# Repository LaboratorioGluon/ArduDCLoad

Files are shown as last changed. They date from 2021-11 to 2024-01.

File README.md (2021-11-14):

# ArduDCLoad	

A configurable multipurpose DC Load board developed directly [on Twitch](https://www.twitch.tv/labgluon)

The values of the resistors can be calculated to adapt the PCB to your needs.

With defaul values máximum values are:
- V_TEST: 15V, 3A
- V_In; 5V

And this is how it looks:

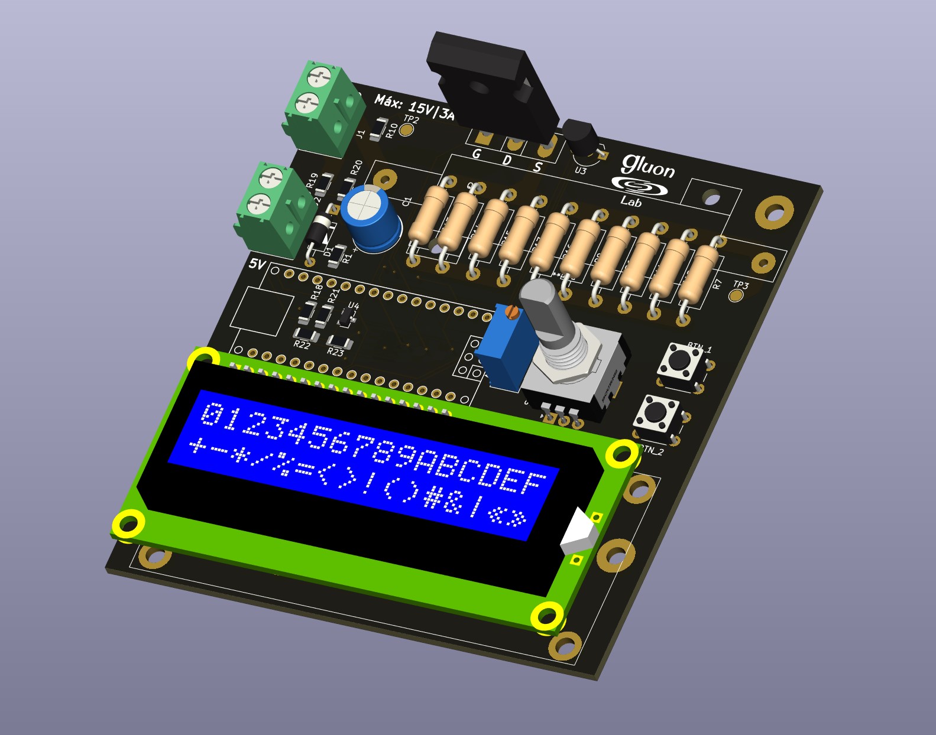
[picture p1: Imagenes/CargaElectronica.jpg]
PCB Image


# Design and customization

Here we will see how to customize the circuit for our need. The ADCL (ArduDCLoad) can be configure to mount a beefy TO-247 or small TO-220 MOSFETS. Also, it also contains the footprint for 10 resistors( L: 10mm, D: 3.6mm, P:15mm) or big chunky wirewound resistor (L:50mm, W:14mm).

Lets see how to adapt it to your need (we will calculate the values for the current values in the design)

## Select V_TEST and I_TEST

Set what do you need for V_TEST and I_TEST. The circuit can only support **around 5-6A** máximum.

In our case

> V_TEST = 15V
> I_TEST = 3A

## Select MOSFET measuring resistor

The ideal values would be between 1 to 0.1 Ohms. The lower the current you expect, the bigget the value should be. In our case, for 3A, with 1 Ohm, we have 3V drop, so we can go with 1 Ohm. (We expect to test more than 3V)

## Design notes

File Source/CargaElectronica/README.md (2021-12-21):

# Design

The software is splitted into 3 components:
- Input : Handling the inputs of the buttons/rotary encoder
- Screen : Send the data to the screen and handle the info and display
- DcLoad : Control the PWM output to control the actual DC Load

# Project Structure + Conventions

- src/
    - taskInput/
        - mainInput.cpp/h
    - taskScreen/
        - mainScreen.cpp/h
    - taskDcLoad/
        - mainDcLoad.cpp/h
    - taskConfig.h
    - globalConfig.h
    - main.cpp

## Tasks

Each task will have a structure with the data it can gather. `struct <component>Data;`

## Naming

```
<component><part>()
ie: inputMainLoop()

```

# System
The system will be Arduino Nano AtMega328p

ADCs:
Interrupts: 

# Components

## Input

- Data:
    - RotaryPulses
    - PushButtons[2]
    - ADC read.
- Period: 100 ms
- Interrupts:
    - 

## Screen

- Data: 
    - Current Mode
    - Current/Power value set.
- Period: 300 ms

### Screens

#### Welcome

Print something like 

---------------
"  Welcome!  "
" ArduDCLoad "
---------------

#### 

## DcLoad

- Data: None
- Period: 50 ms

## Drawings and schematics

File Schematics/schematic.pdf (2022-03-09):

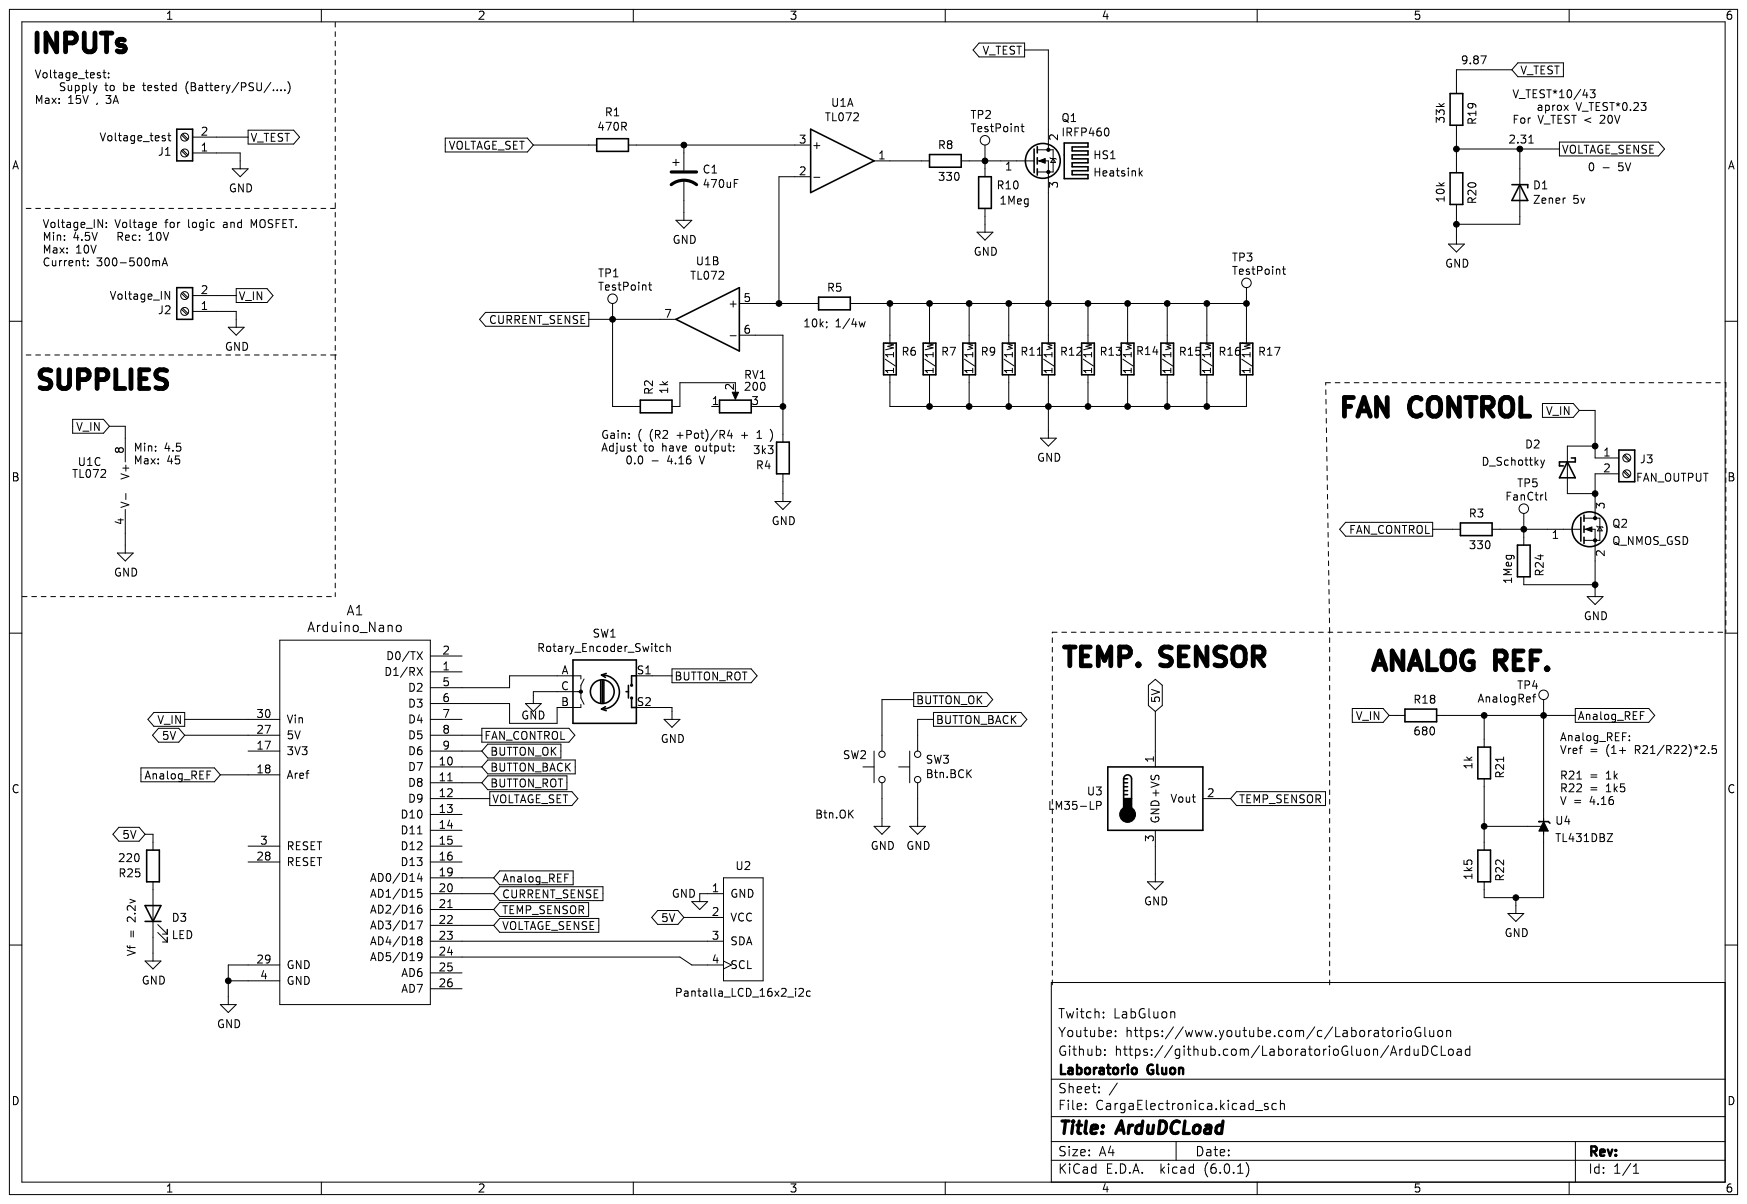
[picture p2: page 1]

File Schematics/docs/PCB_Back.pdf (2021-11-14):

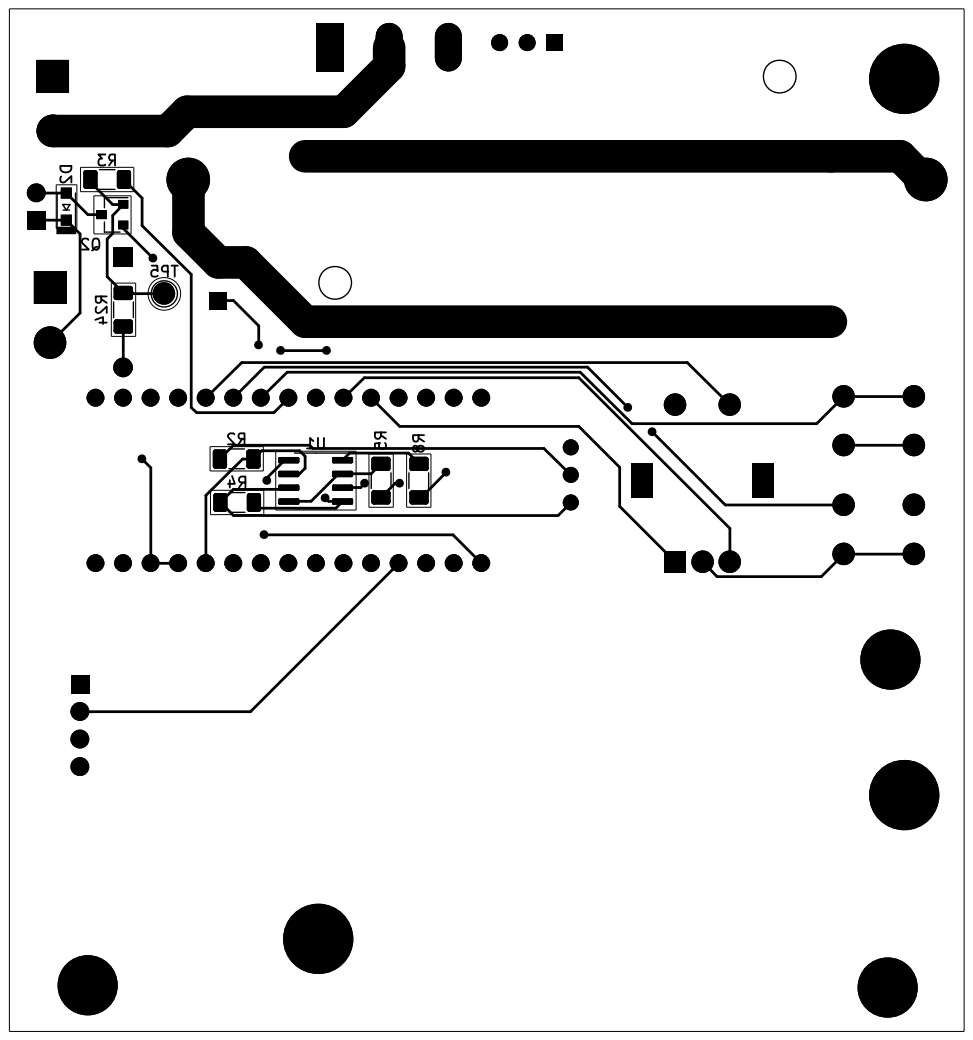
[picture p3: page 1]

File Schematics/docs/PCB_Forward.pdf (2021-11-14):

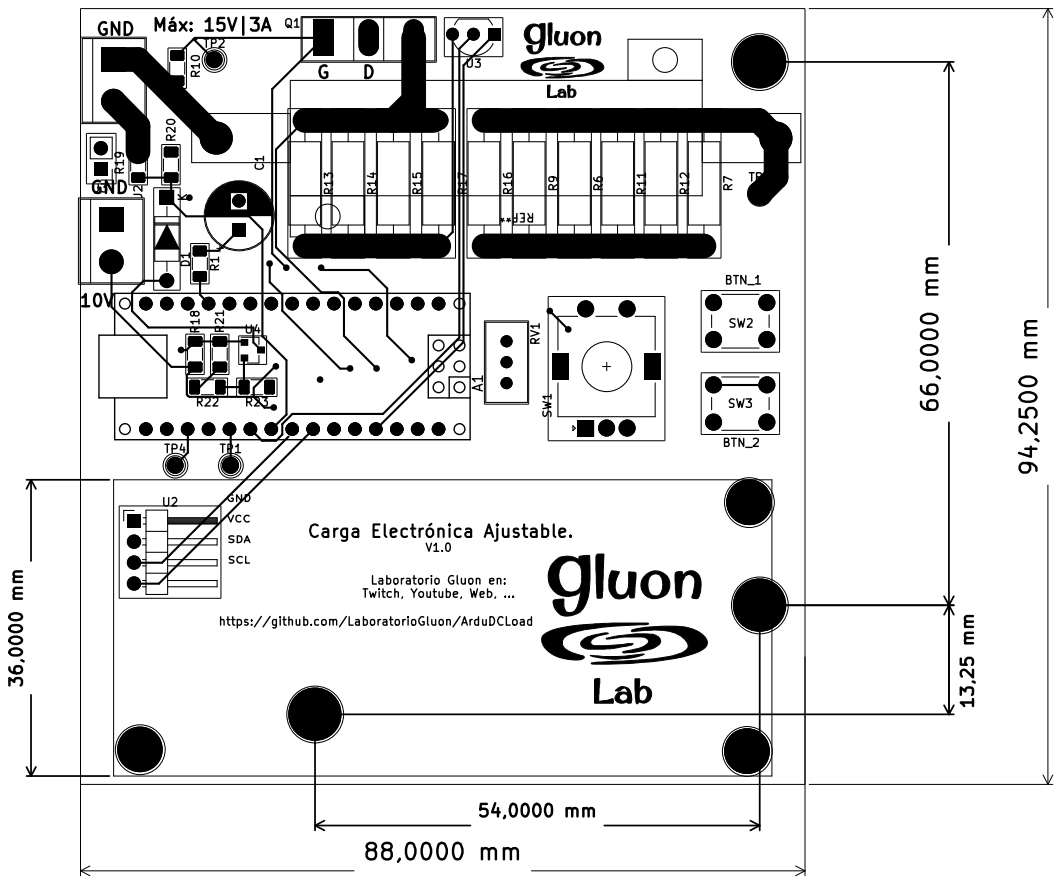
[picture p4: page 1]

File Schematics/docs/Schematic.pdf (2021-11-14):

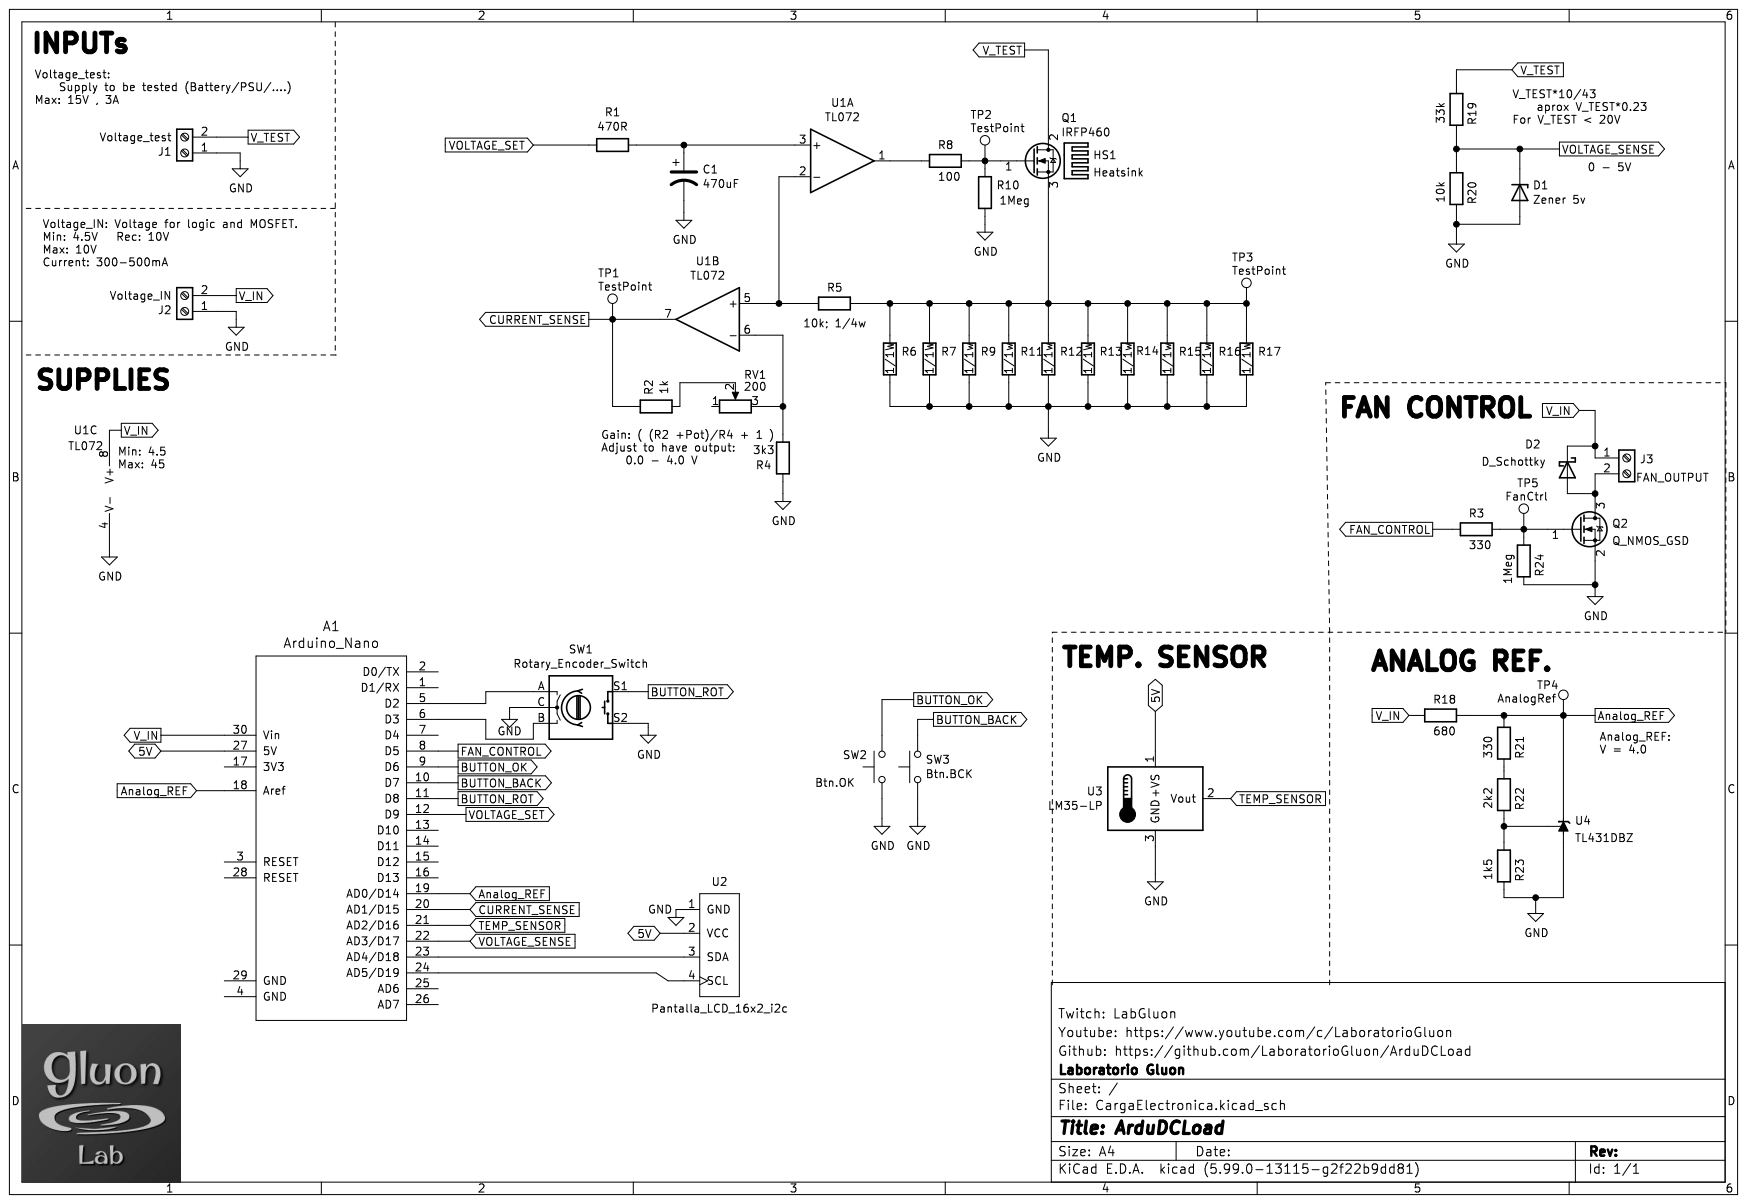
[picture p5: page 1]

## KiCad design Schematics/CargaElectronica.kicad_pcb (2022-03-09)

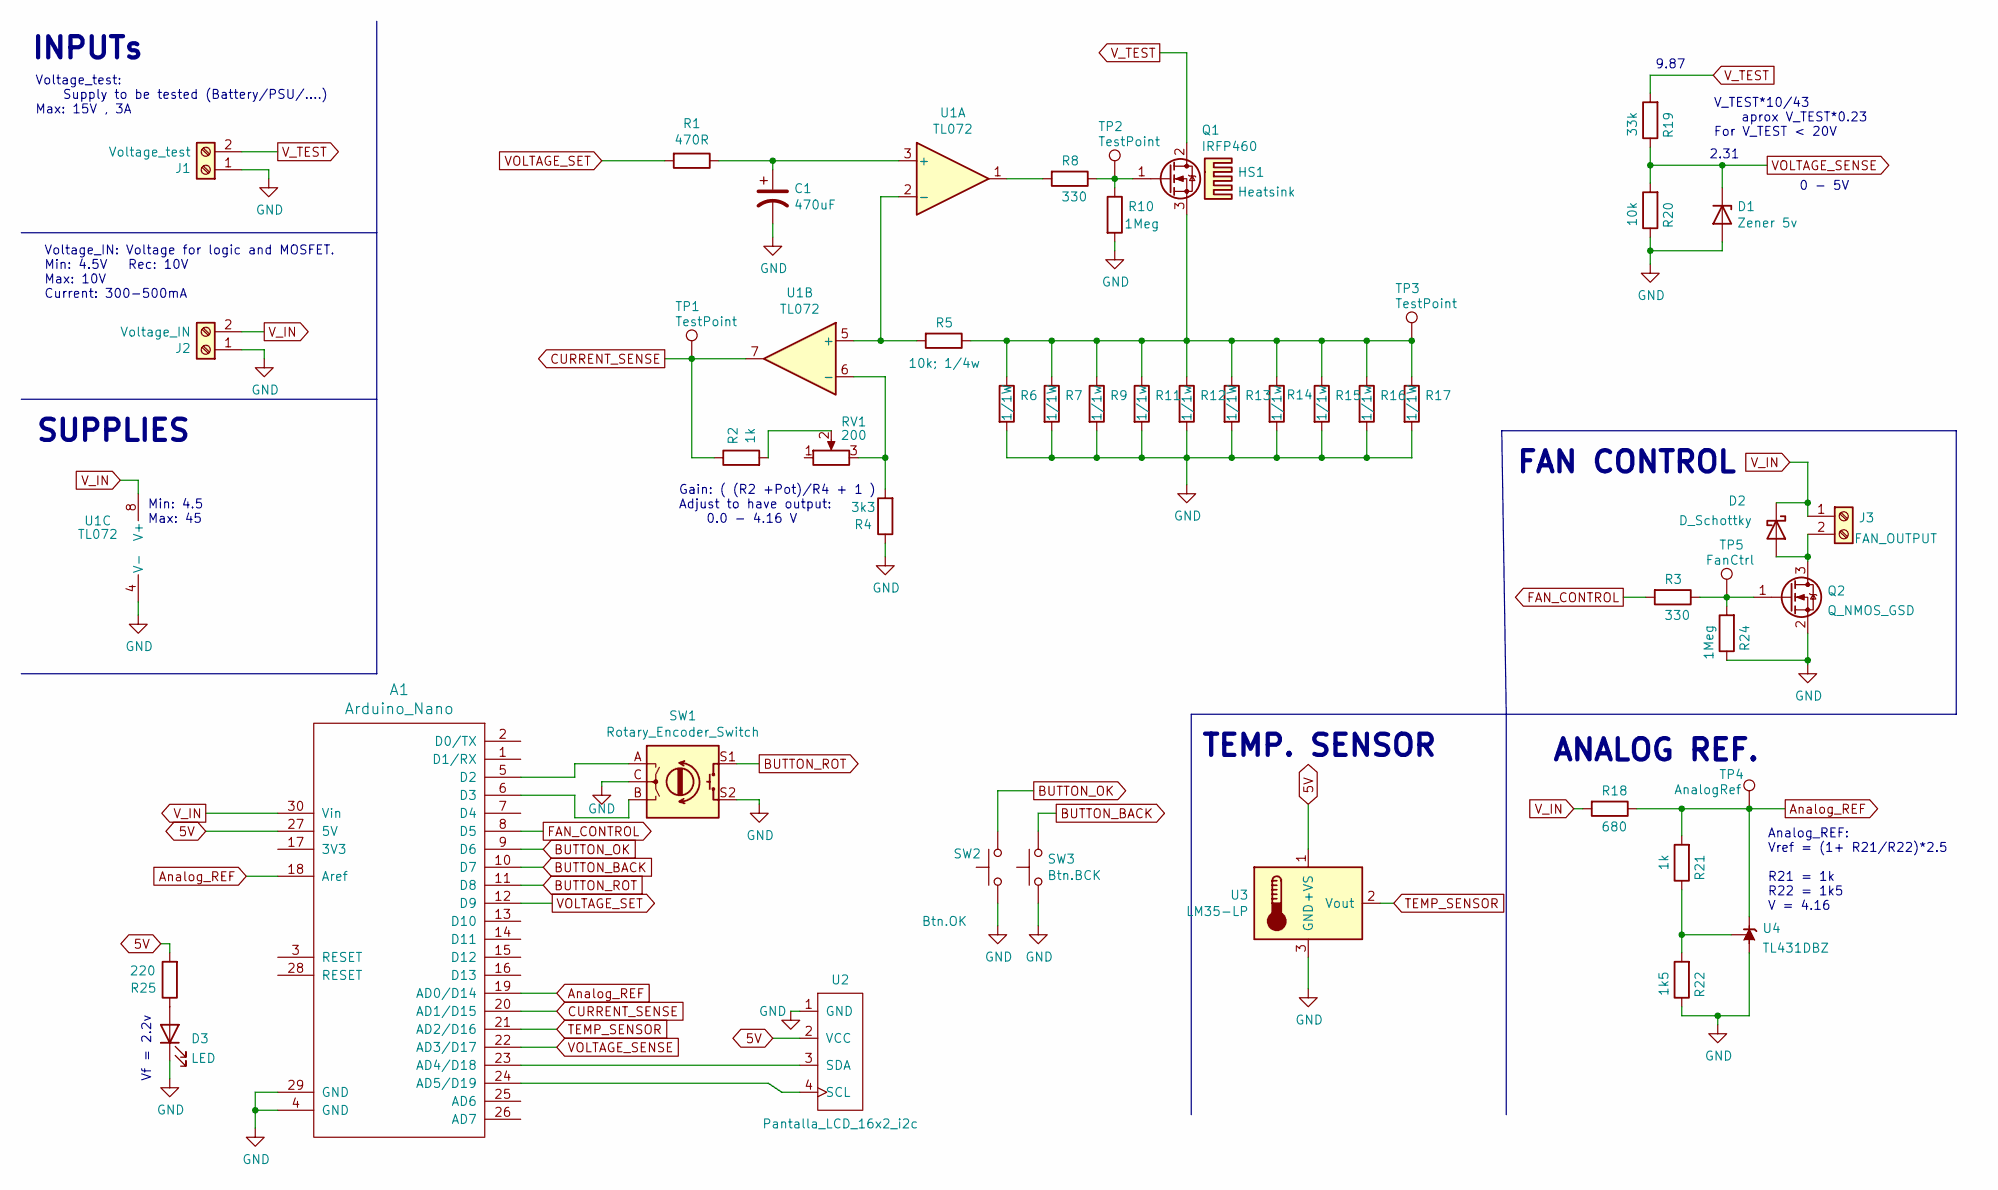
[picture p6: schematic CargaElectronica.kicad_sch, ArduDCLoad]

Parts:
A1: Arduino_Nano; arduino_nano
C1: 470uF; CP_Radial_D8.0mm_P3.50mm
D1: Zener 5v; D_A-405_P10.16mm_Horizontal
D2: D_Schottky; D_SOD-323_HandSoldering
D3: LED; LED_D5.0mm_Horizontal_O1.27mm_Z3.0mm
HS1: Heatsink
J1: Voltage_test; TerminalBlock_bornier-2_P5.08mm
J2: Voltage_IN; TerminalBlock_bornier-2_P5.08mm
J3: FAN_OUTPUT; PinHeader_1x02_P2.54mm_Vertical
Q1: IRFP460; TO-247-3_Vertical
Q2: Q_NMOS_GSD; SOT-23
R1: 470R; R_1206_3216Metric_Pad1.30x1.75mm_HandSolder
R2, R21: 1k; R_1206_3216Metric_Pad1.30x1.75mm_HandSolder
R3, R8: 330; R_1206_3216Metric_Pad1.30x1.75mm_HandSolder
R4: 3k3; R_1206_3216Metric_Pad1.30x1.75mm_HandSolder
R5: 10k; 1/4w; R_1206_3216Metric_Pad1.30x1.75mm_HandSolder
R6, R7, R13, R17: 1/1W; R_Axial_DIN0411_L9.9mm_D3.6mm_P15.24mm_Horizontal
R9, R11, R12, R14, R15, R16: 1/1w; R_Axial_DIN0411_L9.9mm_D3.6mm_P15.24mm_Horizontal
R10, R24: 1Meg; R_1206_3216Metric_Pad1.30x1.75mm_HandSolder
R18: 680; R_1206_3216Metric_Pad1.30x1.75mm_HandSolder
R19: 33k; R_1206_3216Metric_Pad1.30x1.75mm_HandSolder
R20: 10k; R_1206_3216Metric_Pad1.30x1.75mm_HandSolder
R22: 1k5; R_1206_3216Metric_Pad1.30x1.75mm_HandSolder
R25: 220; R_1206_3216Metric_Pad1.30x1.75mm_HandSolder
RV1: 200; Potentiometer_Bourns_3296W_Vertical
SW1: Rotary_Encoder_Switch; RotaryEncoder_Alps_EC11E-Switch_Vertical_H20mm
SW2: Btn.OK; SW_PUSH_6mm_H4.3mm
SW3: Btn.BCK; SW_PUSH_6mm_H4.3mm
TP1, TP2, TP3: TestPoint; TestPoint_Pad_D2.0mm
TP4: AnalogRef; TestPoint_Pad_D2.0mm
TP5: FanCtrl; TestPoint_Pad_D2.0mm
U1: TL072; SOIC-8_3.9x4.9mm_P1.27mm
U2: Pantalla_LCD_16x2_i2c; PinHeader_1x04_P2.54mm_Horizontal
U3: LM35-LP; TO-92_Inline_Wide
U4: TL431DBZ; SOT-23

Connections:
5V: A1.27 (5V), R25.2, U2.2 (VCC), U3.1 (+VS)
Analog_REF: A1.18 (Aref), A1.19 (AD0/D14), R18.1, R21.2, TP4.1, U4.1 (K)
BUTTON_BACK: A1.10 (D7), SW3.2
BUTTON_OK: A1.9 (D6), SW2.2
BUTTON_ROT: A1.11 (D8), SW1.S1
CURRENT_SENSE: A1.20 (AD1/D15), R2.1, TP1.1, U1.7
FAN_CONTROL: A1.8 (D5), R3.2
GND: A1.4 (GND), A1.29 (GND), C1.2, D1.2 (A), D3.1 (K), J1.1, J2.1, Q2.2 (S), R4.1, R6.2, R7.2, R9.2, R10.2, R11.2, R12.2, R13.2, R14.2, R15.2, R16.2, R17.2, R20.1, R22.1, R24.1, SW1.C, SW1.S2, SW2.1, SW3.1, U1.4 (V-), U2.1 (GND), U3.3 (GND), U4.3 (A)
unnamed: A1.5 (D2), SW1.A
unnamed: A1.6 (D3), SW1.B
unnamed: A1.23 (AD4/D18), U2.3 (SDA)
unnamed: A1.24 (AD5/D19), U2.4 (SCL)
unnamed: C1.1, R1.1, U1.3 (+)
unnamed: D2.2 (A), J3.2, Q2.3 (D)
unnamed: D3.2 (A), R25.1
unnamed: Q1.1 (G), R8.1, R10.1, TP2.1
unnamed: Q1.3 (S), R5.1, R6.1, R7.1, R9.1, R11.1, R12.1, R13.1, R14.1, R15.1, R16.1, R17.1, TP3.1
unnamed: Q2.1 (G), R3.1, R24.2, TP5.1
unnamed: R2.2, RV1.2
unnamed: R4.2, RV1.3, U1.6 (-)
unnamed: R5.2, U1.2 (-), U1.5 (+)
unnamed: R8.2, U1.1
unnamed: R21.1, R22.2, U4.2 (REF)
TEMP_SENSOR: A1.21 (AD2/D16), U3.2 (Vout)
VOLTAGE_SENSE: A1.22 (AD3/D17), D1.1 (K), R19.1, R20.2
VOLTAGE_SET: A1.12 (D9), R1.2
V_IN: A1.30 (Vin), D2.1 (K), J2.2, J3.1, R18.2, U1.8 (V+)
V_TEST: J1.2, Q1.2 (D), R19.2

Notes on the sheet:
Min: 4.5 Max: 45
Vf = 2.2v
ANALOG REF.
INPUTs
9.87
V_TEST*10/43 aprox V_TEST*0.23 For V_TEST < 20V
2.31
TEMP. SENSOR
Voltage_test: Supply to be tested (Battery/PSU/....) Max: 15V , 3A
FAN CONTROL
SUPPLIES
Voltage_IN: Voltage for logic and MOSFET. Min: 4.5V Rec: 10V Max: 10V Current: 300-500mA
Analog_REF: Vref = (1+ R21/R22)*2.5 R21 = 1k R22 = 1k5 V = 4.16
Gain: ( (R2 +Pot)/R4 + 1 ) Adjust to have output: 0.0 - 4.16 V
0 - 5V

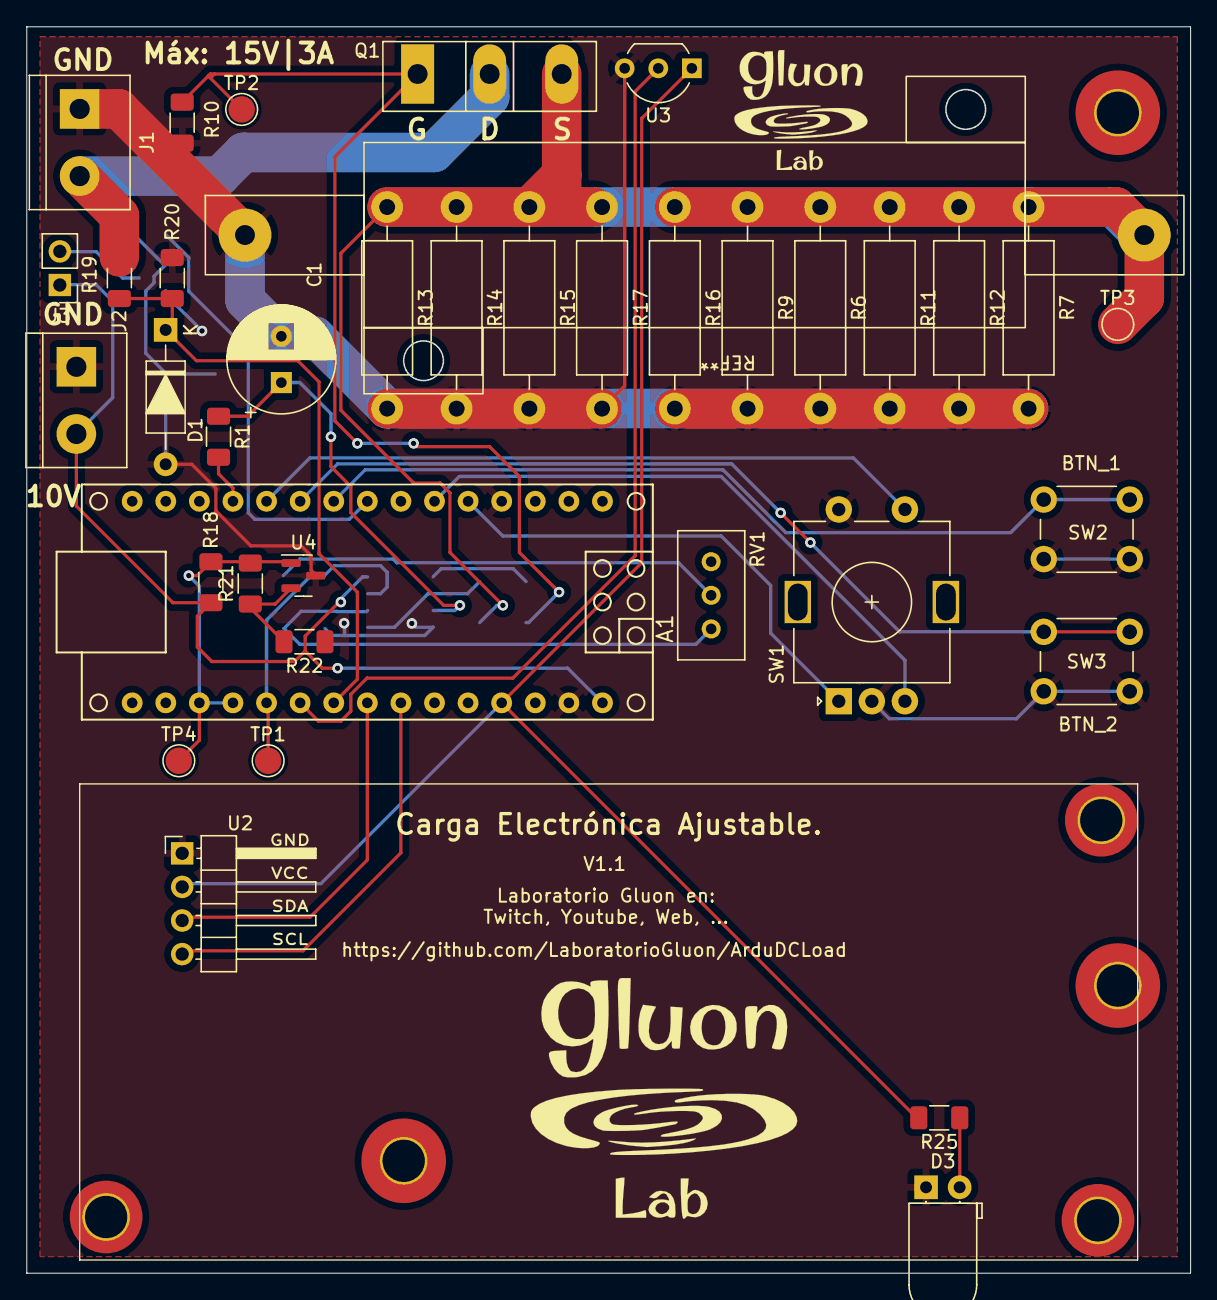
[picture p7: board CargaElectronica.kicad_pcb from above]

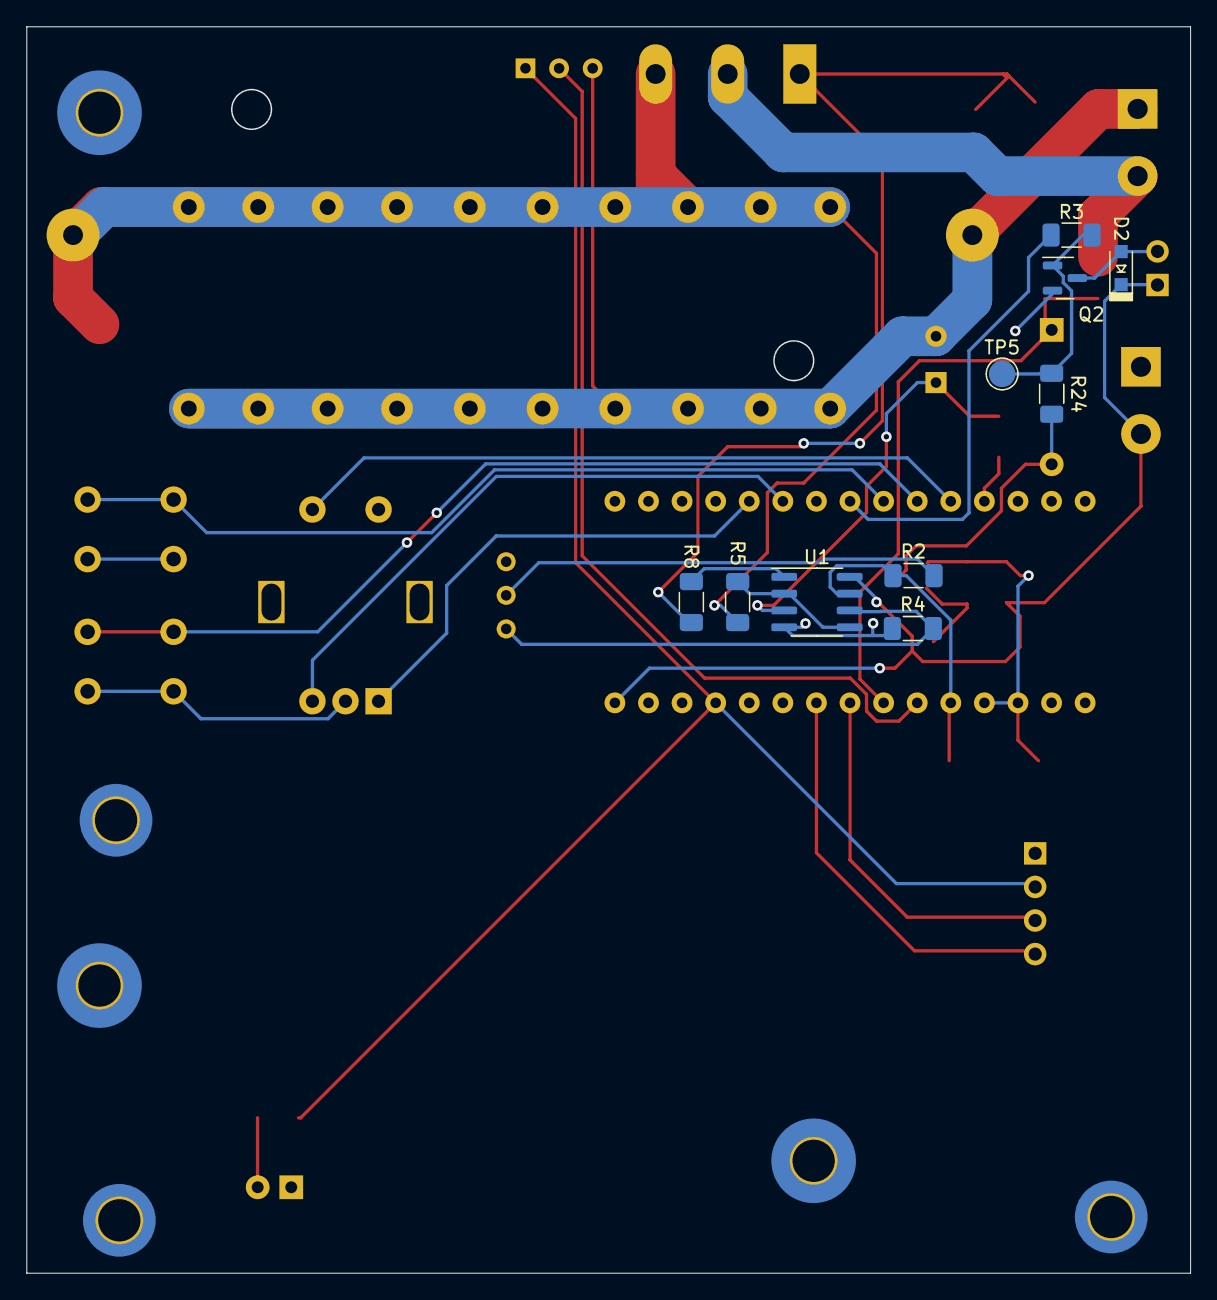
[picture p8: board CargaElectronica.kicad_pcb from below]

Board: 2 copper layers, 88.0 x 94.2 mm, 47 parts (10 on the bottom side), 28 nets.

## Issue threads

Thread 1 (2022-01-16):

Reference voltage circuit is not correct.

LaboratorioGluon, 2022-01-16:
The Reference voltage with the TL431 is not correct.

The Vout equation is Vo = (1 + R1/R2)*Vref.

The current configuration is:
- R1: 2500
- R2: 1500

The Vo is then 6.6V aprox.

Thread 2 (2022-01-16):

Missing ground for Arduino

LaboratorioGluon, 2022-01-16:
The Arduino socket does not have a ground connection.

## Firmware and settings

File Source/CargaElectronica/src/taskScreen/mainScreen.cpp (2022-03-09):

#include "taskScreen/mainScreen.h"
#include "taskScreen/screenTemplates.h"

#include <Arduino.h>

#include <Wire.h>
#include <LiquidCrystal_I2C.h>

#include <stdint.h>

#include "taskInput/mainInput.h"

#include "FSM/fsm.h"

constexpr unsigned long ScreenPeriodMs = 300; // 100ms 

namespace taskScreen {

    struct screenData screenOutData;

    enum screenState {
        SCREEN_WELCOME = 0,
        SCREEN_SHOW_DATA,
        SCREEN_NULL
    };

    enum screenState currentScreenState;
    enum screenState previousScreenState = SCREEN_NULL;

    taskInput::inputData lastInputData;


    LiquidCrystal_I2C lcd(0x27,16,2);

    unsigned long lastMillis;
    unsigned long dt;


    // Internal Functions
    void updateScreen();
    void setScreen(char t[2][17]);
    void internalLoop(unsigned long deltaTime);


    void screenInitialize(){
        currentScreenState = SCREEN_WELCOME;
        lcd.init(); 

        lcd.backlight();
        //setScreen(templatesWelcome);

    }

    

    void screenMainLoop(){

        // Calculate the time since the last call
        dt = millis() - lastMillis;

        if(dt > ScreenPeriodMs){
            #if DEBUG == 1
                //Serial.print("Executing Input Main Loop!");Serial.println(millis());
            #endif
            lastMillis = millis();

            internalLoop(dt);

        }

    }

    void setScreen(char t[2][17]){
            
            lcd.setCursor(0,0);
            lcd.print(t[0]);
            lcd.setCursor(0,1);
            lcd.print(t[1]);
    
    }



    void internalLoop(unsigned long deltaTime){
        fsmScreen(lcd);

#if 0
        if( currentScreenState == SCREEN_WELCOME && 
            taskInput::inputOutData.rotarySwitch == 1 &&
            lastInputData.rotarySwitch == 0){

                currentScreenState = SCREEN_SHOW_DATA;
        }

        updateScreen();

        if (currentScreenState == SCREEN_SHOW_DATA){
            
            char voltage[2];
            char decimals[3];
            char decimals2[3];
            itoa(taskInput::inputOutData.voltageSense/100,voltage,10);
            itoa(taskInput::inputOutData.voltageSense%100,decimals,10);
            
            if (strlen(decimals) == 1){
                decimals2[0] = '0';
                decimals2[1] = decimals[0];
                decimals2[2] = '\0';
            }else{
                decimals2[0] = decimals[0];
                decimals2[1] = decimals[1];
                decimals2[2] = '\0';
            }

            lcd.setCursor(2,1);
            lcd.print(voltage);
            lcd.setCursor(3,1);
            lcd.print('.');
            lcd.setCursor(4,1);
            lcd.print(decimals2);
        }

    
        lastInputData = taskInput::inputOutData;
#endif
    }


    void updateScreen(){
/*
        if(currentScreenState != previousScreenState){
            switch(currentScreenState){
                case SCREEN_WELCOME:
                    setScreen(templatesWelcome);
                    break;
                case SCREEN_SHOW_DATA:
                    setScreen(templateShowValues);
                    break;
            }
            previousScreenState = currentScreenState;
        }
*/
    }

}

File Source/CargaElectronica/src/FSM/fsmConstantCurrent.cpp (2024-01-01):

#include <FSM/fsmConstantCurrent.h>

#include <Arduino.h>

#include "taskInput/mainInput.h"
#include "calibration.h"
#include "globalConfig.h"


char templateShowValues[2][17] ={ " Const.DC      ", "V:     I:     mA"};

uint16_t targetCurrent = 100; //[mA]
uint16_t targetVoltage = 0;
uint16_t multiplier = 1;

uint8_t first_run = 1;

uint8_t isOn = 0;

long setPoint = 0;
float resistorFactor = 0.0f;

void fsmConstantCurrent_process(unsigned long deltaTime){

    if(taskInput::inputOutData.rotarySwitch == 1 && 
        lastInputData.rotarySwitch == 0){

        multiplier *= 10;
        if (multiplier > 1000){
            multiplier = 1;
        }
    }
    if (taskInput::inputOutData.switchOk == 1 &&
        lastInputData.switchOk == 0){
        isOn = isOn?0:1;
    }

    if (taskInput::inputOutData.switchBack == 1 &&
        lastInputData.switchBack == 0){
        fsmNext();
    }
    
    targetCurrent += taskInput::inputOutData.rotaryCounter*multiplier;

    if(targetCurrent > OUTPUT_MAX_CURRENT_MA){
        targetCurrent = OUTPUT_MAX_CURRENT_MA;
    }

    targetVoltage = targetCurrent * CALIBRATION_MAIN_RESISTOR_VALUE / 10.0f; // 10.0f to move from mV to 10mV

    if(isOn){
        
        if(targetVoltage > CALIBRATION_MAX_VOLTAGE10MV){
            targetVoltage = CALIBRATION_MAX_VOLTAGE10MV;
        }

        setPoint = map((float)targetVoltage, 0, 500, 0, 255);
        Serial.println("Setting point: " + String(setPoint));
        analogWrite(9, setPoint);

    }else{

        analogWrite(9,0);
        
    }

    lastInputData = taskInput::inputOutData;

}

void fsmConstantCurrent_screen(LiquidCrystal_I2C lcd){

    if(first_run){
        lcd.setCursor(0,0);
        lcd.print(templateShowValues[0]);
    }

    if (isOn){
        lcd.setCursor( 11,0);
        float power = (taskInput::inputOutData.voltageSense / V_TO_100MV) * (targetCurrent / 1000.0f);
        if (power >= 10.0f){
            lcd.print(power, 1);
        }else{
            lcd.print(power, 2);
        }
        lcd.setCursor(15,0);
        lcd.print("W");

        if(power > 15.0f){
            digitalWrite(DCLOAD_FAN_OUTPUT_PIN, HIGH);
        }
    }
    
    // Repintamos segunda linea
    lcd.setCursor(0,1);
    lcd.print(templateShowValues[1]);

    // Marcamos si la fuente está activa o no
    lcd.setCursor(0,0);
    if(isOn){   
        lcd.print('X');
    }else{
        lcd.print(' ');
    }

    
    uint8_t lenStringCurrent = (uint8_t)(floor(log10f(targetCurrent)));

    lcd.setCursor(2,1);
    if (taskInput::inputOutData.voltageSense > 1000){
        lcd.print((float)(taskInput::inputOutData.voltageSense/100.0f), 1);
    }else{
        lcd.print((float)(taskInput::inputOutData.voltageSense/100.0f), 2);
    }
    
    lcd.setCursor(9+3-lenStringCurrent,1);
    lcd.print(targetCurrent);
    lcd.cursor();
    lcd.setCursor(9 + 3 - (uint8_t)(floor(log10f(multiplier))) , 1);

    first_run = 0;

}

void fsmConstantCurrent_endState(){
    if(isOn){
        analogWrite(9,0);
        isOn = false;
    }
    first_run = 1;
}

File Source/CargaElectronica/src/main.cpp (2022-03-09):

#include <Arduino.h>
#include <Wire.h>
#include "taskInput/mainInput.h"
#include "taskDcLoad/mainDcLoad.h"
#include "taskScreen/mainScreen.h"

#include "FSM/fsm.h"

#include "FSM/fsmConstantCurrent.h"
#include "FSM/fsmWelcome.h"
#include "FSM/fsmMppt.h"

/*
#include <RotaryEncoder.h>
extern RotaryEncoder encoder;
*/

void setup() {


  Serial.begin(9600);

  taskInput::inputInitialize();
  taskDcLoad::dcLoadInitialize();
  taskScreen::screenInitialize();

  states[STATE_WELCOME].process = fsmWelcome_process;
  states[STATE_WELCOME].screen = fsmWelcome_screen;
  states[STATE_WELCOME].nextState = STATE_CONSTANT_CURRENT;

  states[STATE_CONSTANT_CURRENT].process = fsmConstantCurrent_process;
  states[STATE_CONSTANT_CURRENT].screen = fsmConstantCurrent_screen;
  states[STATE_CONSTANT_CURRENT].endState= fsmConstantCurrent_endState;
  states[STATE_CONSTANT_CURRENT].nextState = STATE_MPPT;

  states[STATE_MPPT].process = fsmMppt_process;
  states[STATE_MPPT].screen = fsmMppt_screen;
  states[STATE_MPPT].nextState = STATE_CONSTANT_CURRENT;


  fsmCurrentState = STATE_WELCOME;

}

void loop()
{
    
    taskInput::inputMainLoop();
    taskDcLoad::dcLoadMainLoop();
    taskScreen::screenMainLoop();

}

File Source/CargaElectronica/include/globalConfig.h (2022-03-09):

#ifndef __GLOBALCONFIG_H__
#define __GLOBALCONFIG_H__

#define DEBUG 1

// INTERNAL CONVERSIONS
#define V_TO_100MV 100.0f

// CONFIG
#define OUTPUT_MAX_CURRENT_MA 3000
#define INPUT_ADC_REPEATS 10

// INPUTS
#define INPUT_ROTARY_PIN_A 2 
#define INPUT_ROTARY_PIN_B 3
#define INPUT_ROTARY_PIN_SWITCH 8

#define INPUT_BUTTON_OK_PIN 6
#define INPUT_BUTTON_BACK_PIN 7

#define INPUT_ANALOG_REF_PIN    A0
#define INPUT_CURRENT_SENSE_PIN A1
#define INPUT_TEMPERATURE_PIN   A2
#define INPUT_VOLTAGE_SENSE_PIN A3


// OUTPUTS
#define DCLOAD_VOLTAGE_SET_PIN 9
#define DCLOAD_FAN_OUTPUT_PIN  5 


#endif //__GLOBALCONFIG_H__

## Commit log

2021-11-13 PCB, Schematic, code not valid
    [CargaElectronica.kicad_pcb, CargaElectronica.kicad_sch, CargaElectronica.sch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]
2021-11-13 Imagen y documentos de la PCB
    [CargaElectronica.kicad_sch]
2021-11-13 Modified PCB
    [CargaElectronica.kicad_pcb]
2021-11-13 Changed the PCB image
2021-11-14 Added Fan interface
2021-11-14 Updated schematic, did not update with last commit
    [CargaElectronica.kicad_pcb, CargaElectronica.kicad_sch]
2021-12-09 Intermediate commit, pre-update to new kicad
    [CargaElectronica.kicad_pcb, CargaElectronica.kicad_sch]
2021-12-09 Fixed errors in PCB routing
    [CargaElectronica.kicad_pcb, CargaElectronica.kicad_sch]
2021-12-12 Intermediate commit
    [CargaElectronica.kicad_pcb]
2021-12-12 Version 1.1, fixes de la PCB
    [CargaElectronica.kicad_pcb]
2021-12-21 Fix for PCB v1 and more sourcecode
    [CargaElectronica.kicad_pcb, CargaElectronica.kicad_sch]
2022-03-09 Version stable
    [CargaElectronica.kicad_pcb, CargaElectronica.kicad_sch]
